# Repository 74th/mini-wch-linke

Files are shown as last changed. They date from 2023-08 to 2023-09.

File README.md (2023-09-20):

# MINI WCH-LinkE

WCH-LinkE Clone

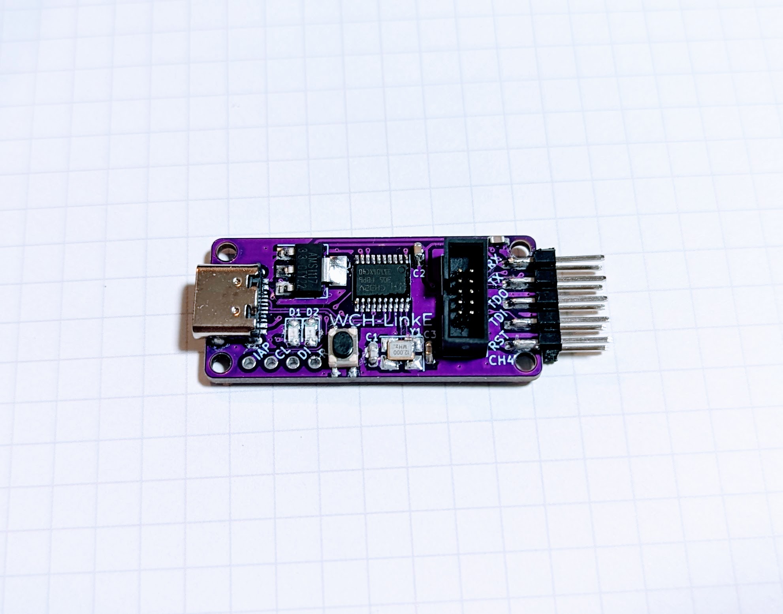
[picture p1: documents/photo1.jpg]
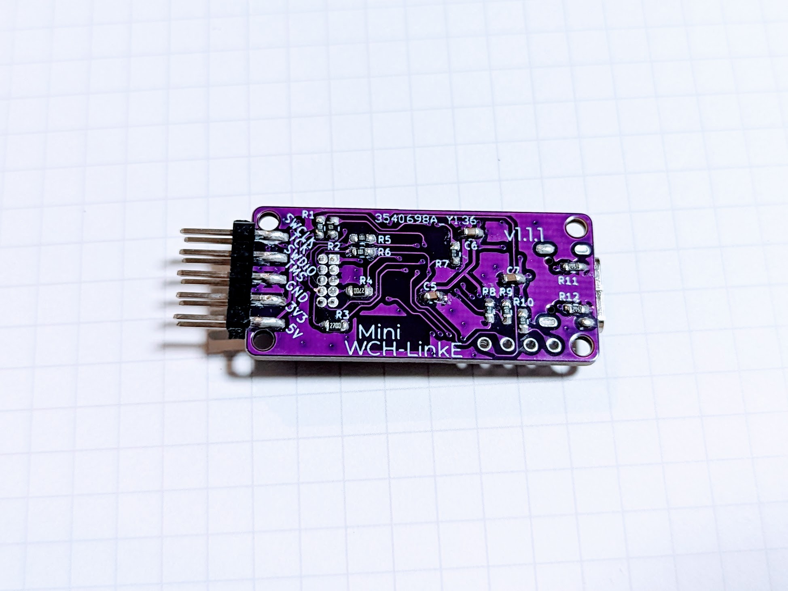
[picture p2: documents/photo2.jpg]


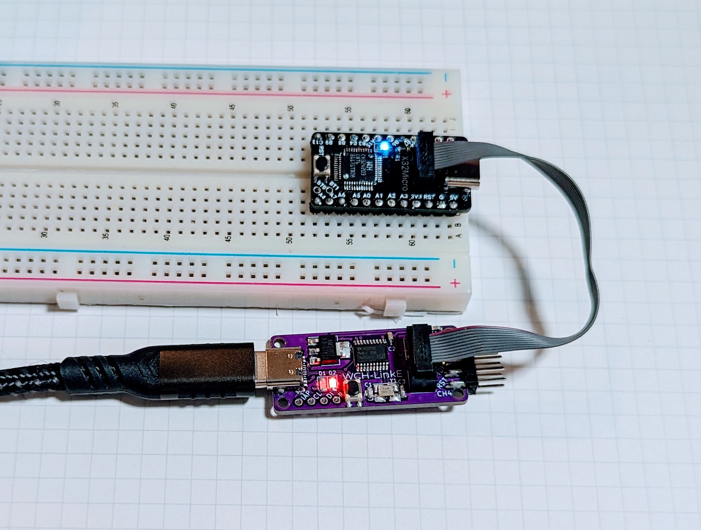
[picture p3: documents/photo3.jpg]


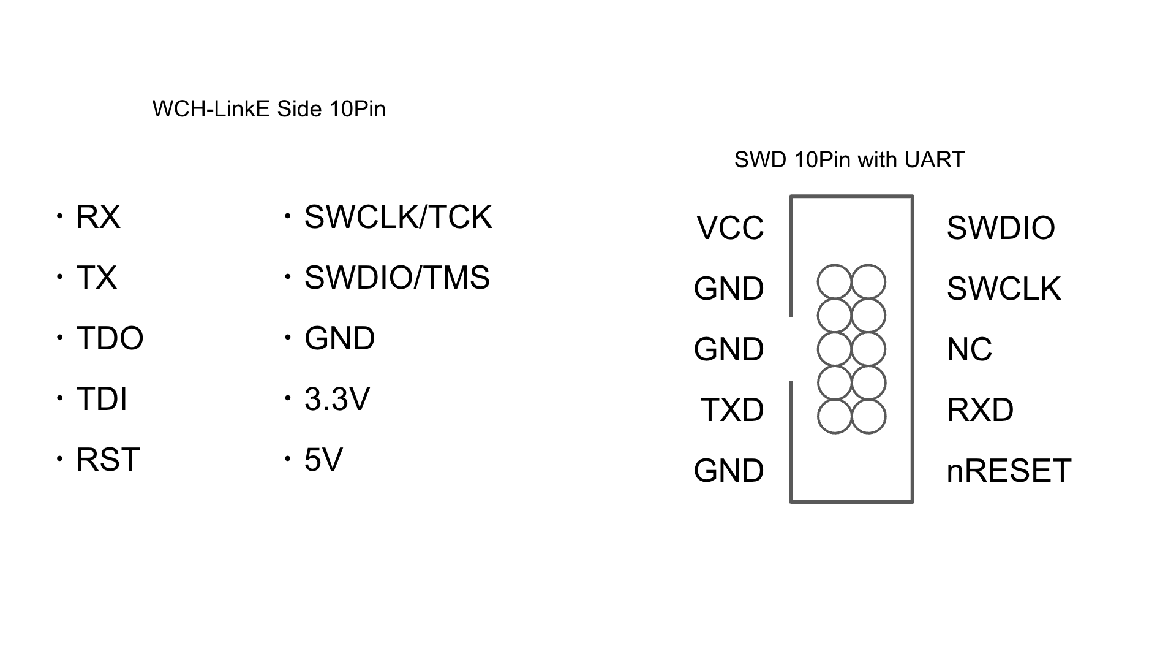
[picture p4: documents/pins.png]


- Shop Site: [BOOTH](https://74th.booth.pm/items/5022813)

## Features

- Arduino UNO R4-like SWD with UART 1.26mm 10-pin added. VCC is 3.3V.
- USB Type-C

## v1.1.1

- semantics: [PDF](documents/mini-wch-linke-v1.1.1.pdf) [kicanvas](https://kicanvas.org/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)
- pcb: [kicanvas](https://kicanvas.org/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)

### BOM

| Reference | Name | Quantity |
| --- | --- | --- |
| C1, C3 | Capacitor 0603 22pF | 2 |
| C2, C4, C6, C7 | Capacitor 0603 10uF | 4 |
| C5 | Capacitor 0603 100nF | 1 |
| CH4 | Pin Header 2x5 Pitch 2.54mm | 1 |
| D1 | LED 0805 BLUE | 1 |
| D2 | LED 0805 RED | 1 |
| J1 | USB Type-C Receptacle - USB | 1 |
| J2 | Box Pin Header 2x5 Pitch 1.27mm | 1 |
| R1, R2, R5, R6 | Register 0603 100Ω | 4 |
| R3, R4 | Register 0603 270Ω | 2 |
| R7, R8 | Register 0603 1kΩ | 2 |
| R9, R10 | Register 0603 10kΩ | 2 |
| R11, R12 | Register 0603 5.1kΩ | 2 |
| SW1 | Button SKRPABE010 | 1 |
| U1 | Regulator 3.3V SOT-223 AMS1117-3.3 | 1 |
| U2 | MCU LQFP48 WCH CH32V305FBP6 | 1 |
| Y1 | Crystal 3225 12MHz | 1 |

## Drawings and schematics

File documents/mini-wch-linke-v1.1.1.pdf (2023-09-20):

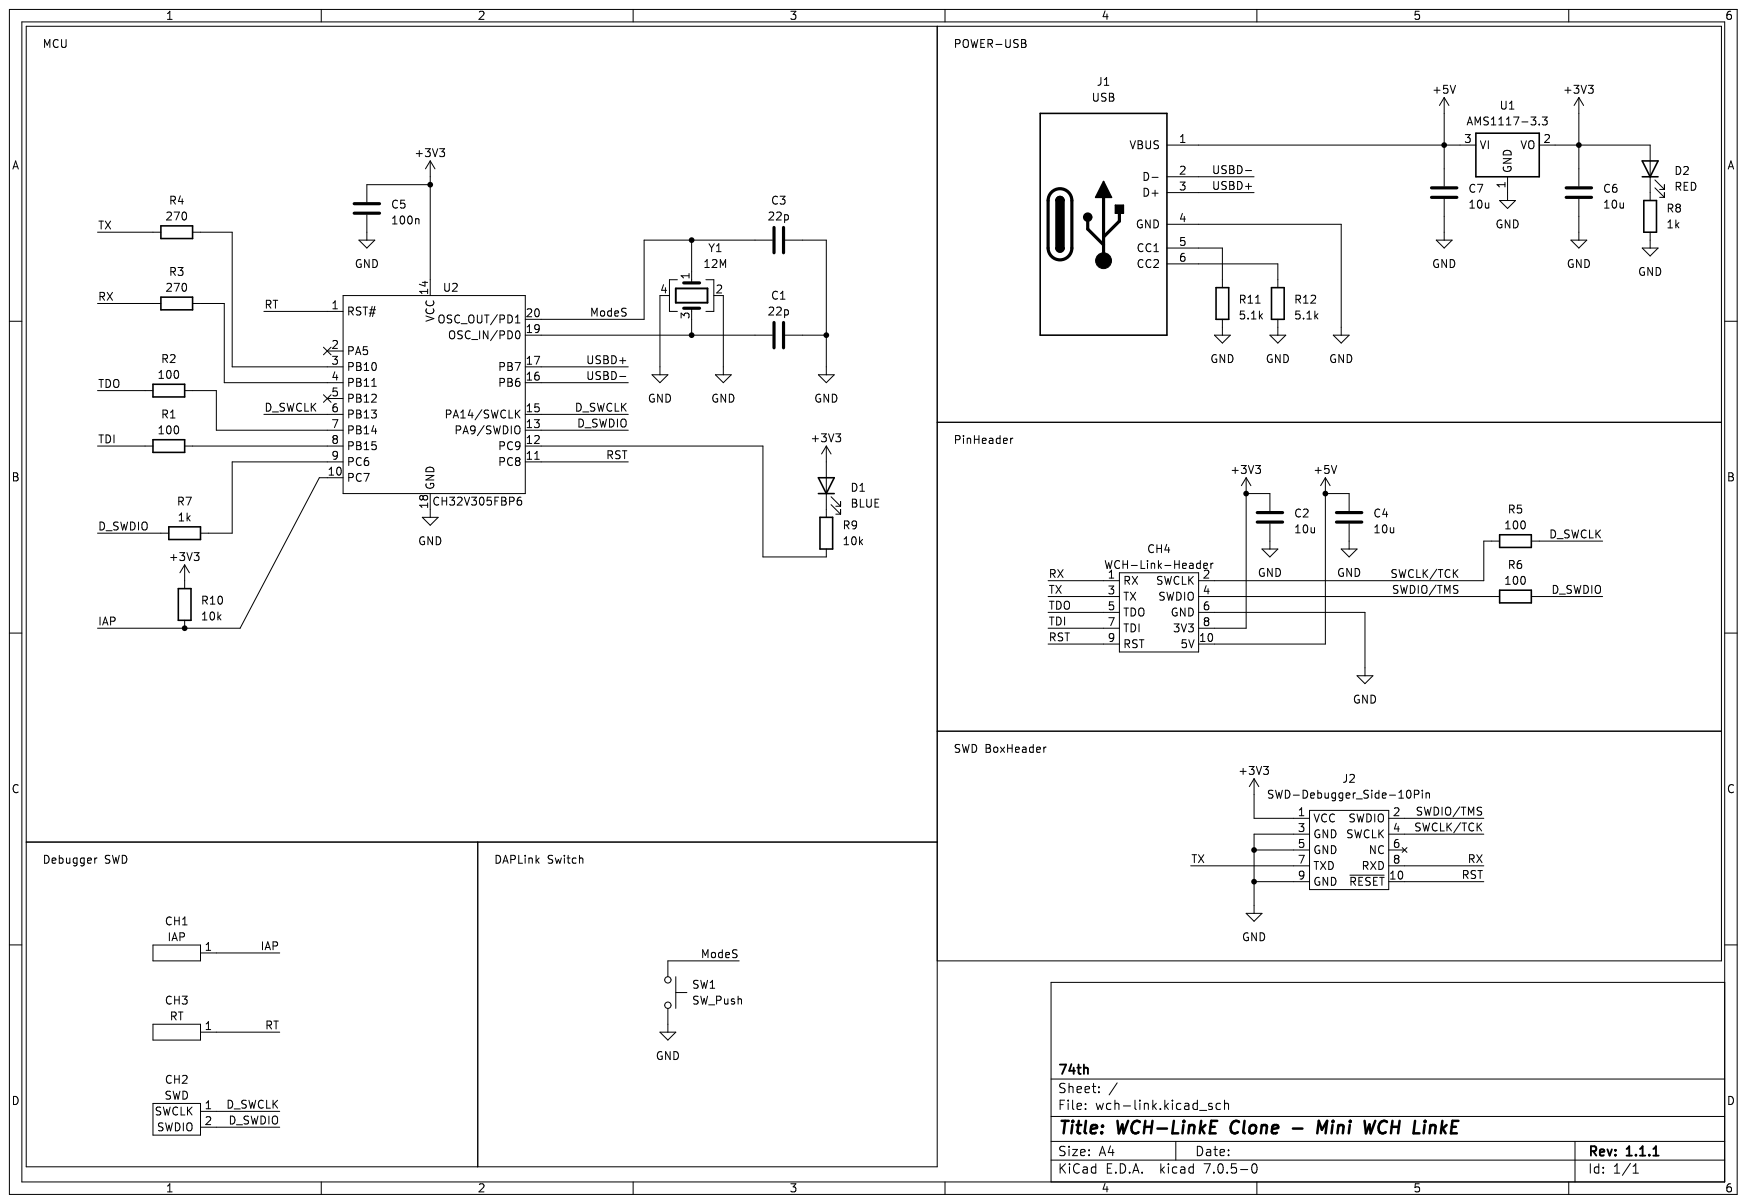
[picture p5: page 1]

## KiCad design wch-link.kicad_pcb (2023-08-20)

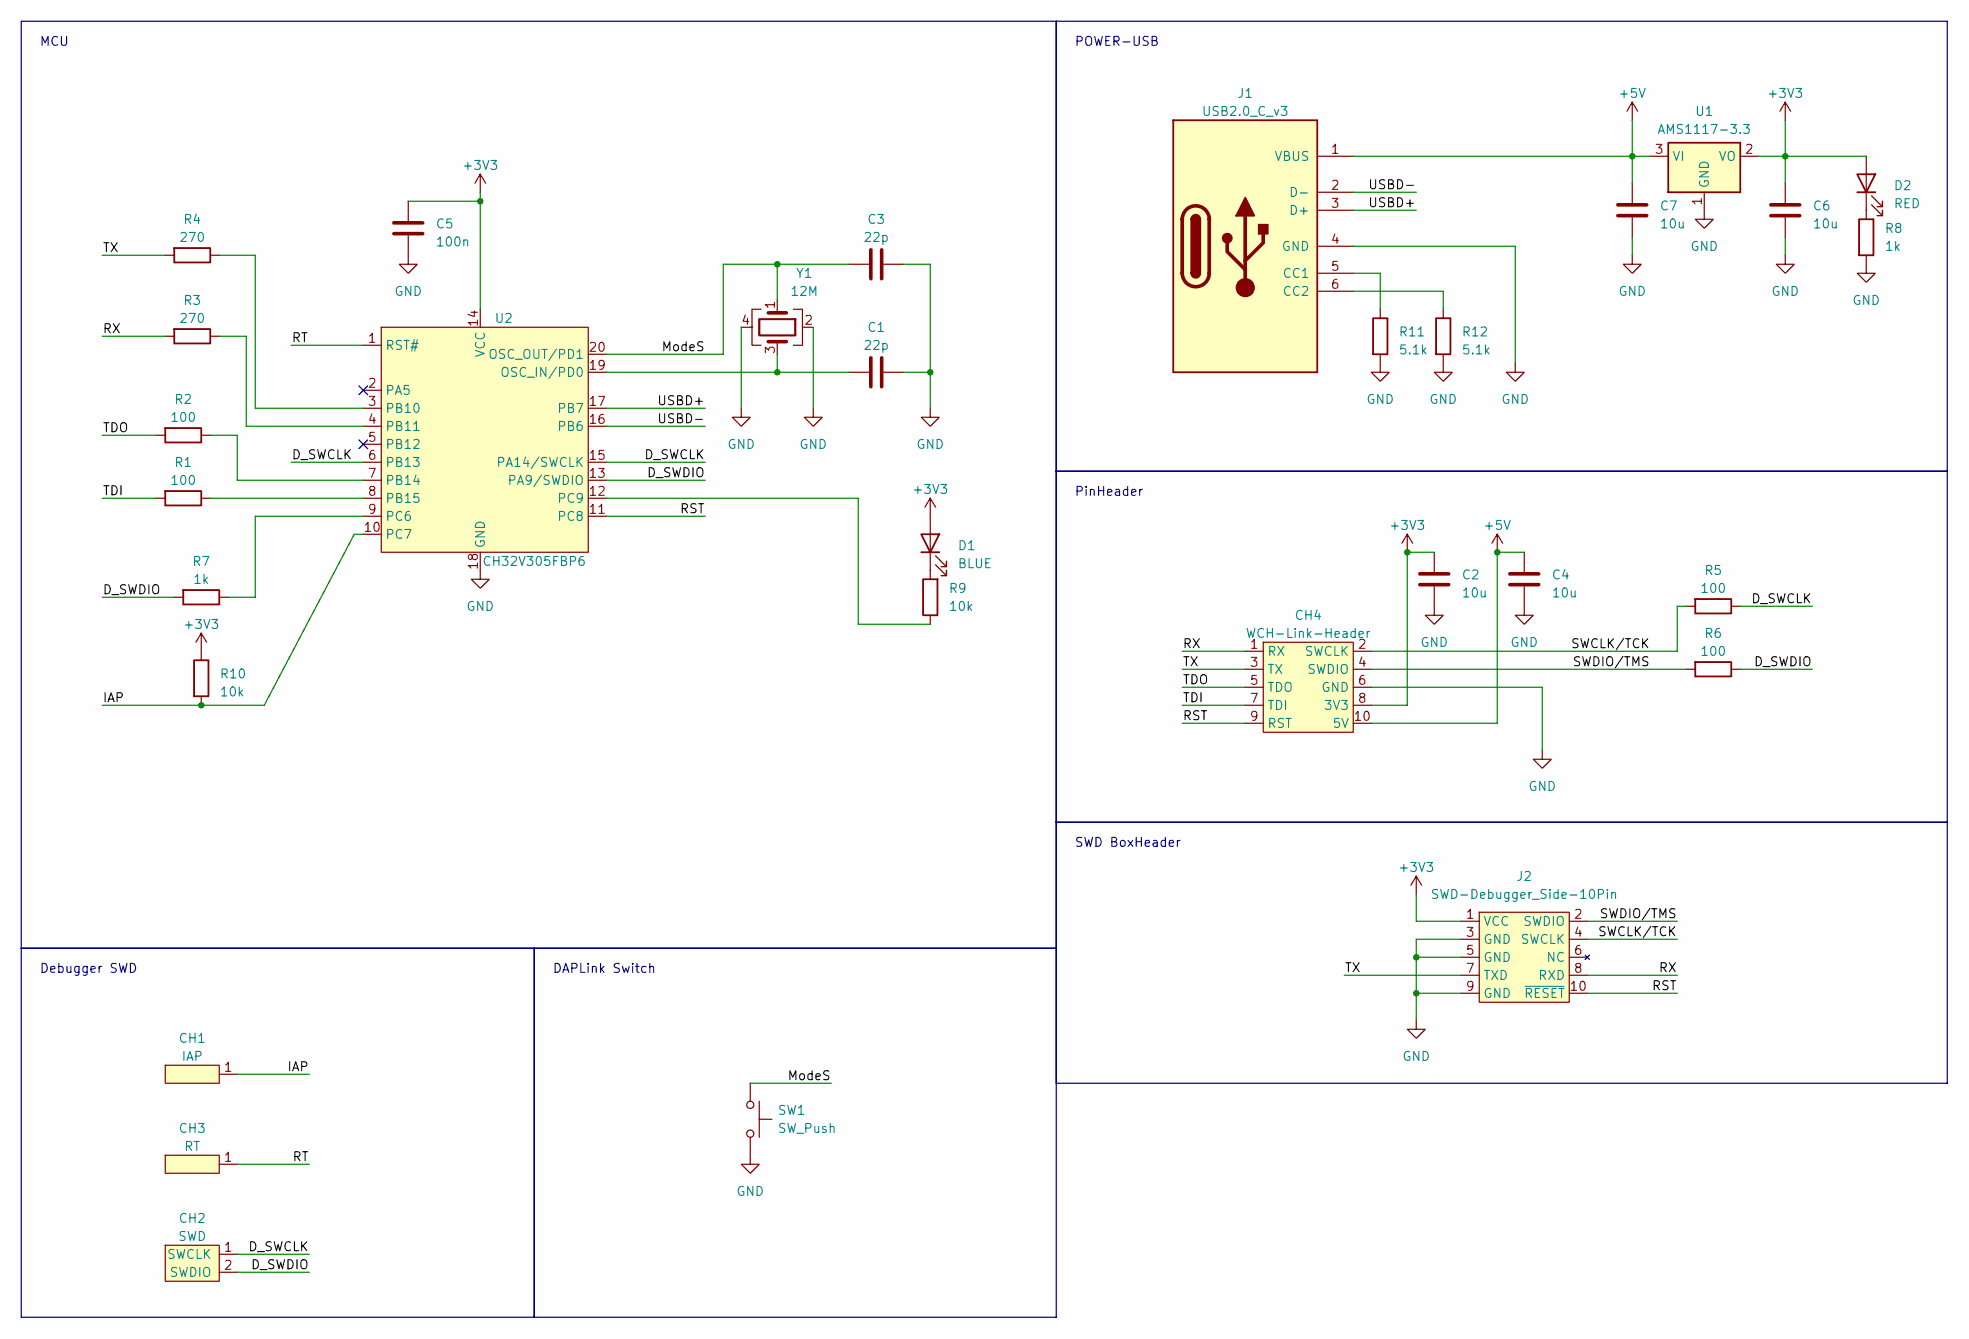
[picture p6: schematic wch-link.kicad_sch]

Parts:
C1, C3: 22p; Capacitor_0603_1608
C2, C4, C6, C7: 10u; Capacitor_0603_1608
C5: 100n; Capacitor_0603_1608
CH1: IAP; 1Pin
CH2: SWD; 2Pin
CH3: RT; 1Pin
CH4: WCH-Link-Header; Side-2x5P-PinHeader-Right
D1: BLUE; LED_0805_2012Metric_Pad1.15x1.40mm_HandSolder
D2: RED; LED_0805_2012Metric_Pad1.15x1.40mm_HandSolder
J1: USB2.0_C_v3; USB-C-12-Pin-SMD
J2: SWD-Debugger_Side-10Pin; BoxPinHeader_2x05_P1.27mm_Vertical
R1, R2, R5, R6: 100; Register_0603_1608
R3, R4: 270; Register_0603_1608
R7, R8: 1k; Register_0603_1608
R9, R10: 10k; Register_0603_1608
R11, R12: 5.1k; Register_0603_1608
SW1: SW_Push; SKRPABE010
U1: AMS1117-3.3; SOT-223-3_TabPin2
U2: CH32V305FBP6; TSSOP-20_4.4x6.5mm_P0.65mm
Y1: 12M; Crystal_SMD_3225-4Pin_3.2x2.5mm_HandSoldering

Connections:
+3V3: C2.2, C5.1, C6.1, CH4.8 (3V3), D1.2 (A), D2.2 (A), J2.1 (VCC), R10.1, U1.2 (VO), U2.14 (VCC)
+5V: C4.2, C7.1, CH4.10 (5V), J1.1 (VBUS), U1.3 (VI)
/D_SWCLK: CH2.1 (SWCLK), R5.1, U2.6 (PB13), U2.15 (PA14/SWCLK)
/D_SWDIO: CH2.2 (SWDIO), R6.1, R7.2, U2.13 (PA9/SWDIO)
/IAP: CH1.1, R10.2, U2.10 (PC7)
/ModeS: C3.2, SW1.1, U2.20 (OSC_OUT/PD1), Y1.1
/RST: CH4.9 (RST), J2.10 (~RESET), U2.11 (PC8)
/RT: CH3.1, U2.1 (RST#)
/RX: CH4.1 (RX), J2.8 (RXD), R3.2
/SWCLK/TCK: CH4.2 (SWCLK), J2.4 (SWCLK), R5.2
/SWDIO/TMS: CH4.4 (SWDIO), J2.2 (SWDIO), R6.2
/TDI: CH4.7 (TDI), R1.2
/TDO: CH4.5 (TDO), R2.2
/TX: CH4.3 (TX), J2.7 (TXD), R4.2
/USBD+: J1.3 (D+), U2.17 (PB7)
/USBD-: J1.2 (D-), U2.16 (PB6)
GND: C1.1, C2.1, C3.1, C4.1, C5.2, C6.2, C7.2, CH4.6 (GND), J1.4 (GND), J2.3 (GND), J2.5 (GND), J2.9 (GND), R8.2, R11.2, R12.2, SW1.2, U1.1 (GND), U2.18 (GND), Y1.2, Y1.4
unnamed: D1.1 (K), R9.2
unnamed: D2.1 (K), R8.1
unnamed: J1.5 (CC1), R11.1
unnamed: J1.6 (CC2), R12.1
unnamed: C1.2, U2.19 (OSC_IN/PD0), Y1.3
unnamed: R4.1, U2.3 (PB10)
unnamed: R3.1, U2.4 (PB11)
unnamed: R2.1, U2.7 (PB14)
unnamed: R1.1, U2.8 (PB15)
unnamed: R7.1, U2.9 (PC6)
unnamed: R9.1, U2.12 (PC9)

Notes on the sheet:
SWD BoxHeader
PinHeader
Debugger SWD
MCU
DAPLink Switch
POWER-USB

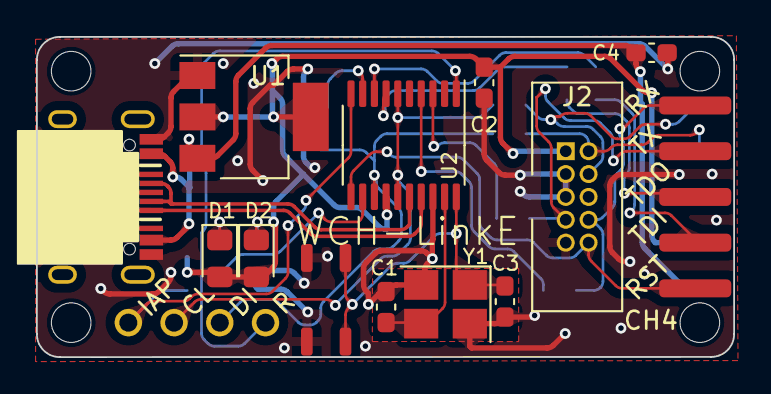
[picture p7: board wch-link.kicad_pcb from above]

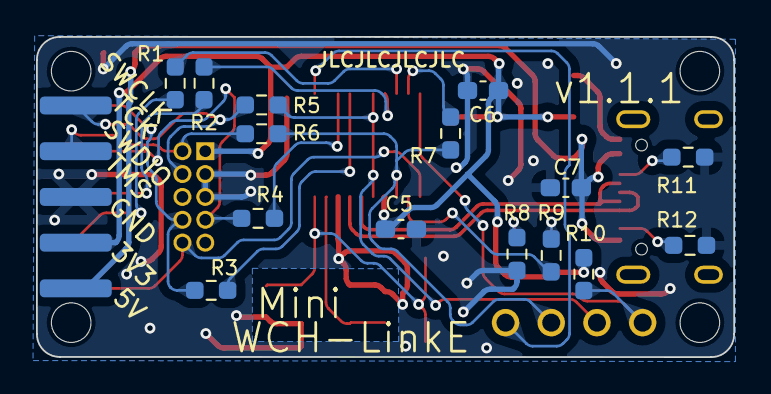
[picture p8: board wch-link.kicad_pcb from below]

Board: 2 copper layers, 38.7 x 17.8 mm, 35 parts (15 on the bottom side), 28 nets.

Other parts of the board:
M1, M2, M3, M4: M2-Hole
